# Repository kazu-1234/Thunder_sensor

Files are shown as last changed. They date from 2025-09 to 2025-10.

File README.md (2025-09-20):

# 多機能雷センサー for Raspberry Pi Pico 2 W

## 概要

Raspberry Pi Pico 2 Wを使用し、雷がどれくらいの距離で発生したかを推定し、同時に温度と湿度を常時監視します。収集したデータは、Wi-Fiを経由してGoogleスプレッドシートに自動的に記録されます。
雷は真上(1Km)～40Kmまで測定することができます。雷を受信すると距離がLINEに送信されるため、パソコンのリモートデスクトップ使用時など雷による被害を防ぐことができます。

またこのデバイスのボタン操作一つでSwitchBotに接続された照明やエアコン、テレビなどの家電を遠隔操作したり、パソコンをwake on lanで起動したりすることができます。

## インストール

### 1. 必要なもの（ハードウェア）
各コンポーネントの役割を理解することで、組み立てがスムーズになります。

   * **Raspberry Pi Pico W:** プロジェクト全体の頭脳。Wi-Fi機能を内蔵しており、ネットワーク通信を担います。
   * **雷センサーモジュール (SparkFun AS3935):** 雷が発する特有の電波を捉え、雷雲までのおおよその距離を算出します。人工的な電気ノイズと雷を区別する高度な機能を持ちます。
   * **温湿度センサー (DFRobot DHT20):** 周囲の温度と湿度を測定します。環境のモニタリングに不可欠です。
   * **LCDディスプレイ (I2C接続 20x4):** 測定データやメニュー、ステータスを表示する情報画面です。I2C接続タイプは少ない配線で済むのが利点です。
   * **その他:**
     - **タクトスイッチ:** ユーザーがメニューを操作するための入力装置です。
     - **フルカラーLED:** デバイスの状態（Wi-Fi接続中、雷検知など）を色で直感的に知らせます。
     - **抵抗、ブレッドボード、ジャンパーワイヤー:** 各部品を電気的に正しく接続するための基本的な電子工作部品です。

### 2. 必要なもの（ソフトウェア・ライブラリ）
Arduino IDEをプログラミング環境として使用します。

   * **Arduino IDE:** Raspberry Pi Picoボードパッケージを事前にインストールしておいてください。
   * **必要なライブラリ：** IDEのライブラリマネージャから以下のものをインストールします。
     - `WiFi`, `WiFiServer`, `WiFiClientSecure`, `HTTPClient`, `Wire`: Pico 2 Wの基本的なネットワーク機能とI2C通信に必要です。
     - `LiquidCrystal_I2C`: I2C接続のLCDを簡単に制御するために使用します。
     - `WiFiNTP`: 正確な時刻をインターネット経由で取得します。
     - `DFRobot_DHT20`: 温湿度センサーからのデータ読み取りに使用します。
     - `SparkFun AS3935 Lightning Detector`: 雷センサーを制御するための専用ライブラリです。
     - `ArduinoJson`: 外部APIとの通信データ（JSON形式）を扱うために重要です。
     - `ArduinoOTA`: Wi-Fi経由でプログラムを書き換える（無線アップデート）ために使用します。

### 3. 設定
ハードウェアとソフトウェアを連携させるための重要なステップです。

   * **ハードウェアの配線:** スケッチ（プログラムコード）内の`namespace Pins`セクションに、どの部品をPico 2 Wのどのピン（GP0, GP1など）に接続するかが定義されています。この定義通りに、ジャンパーワイヤーを使って正確に配線してください。特にI2Cデバイス（雷センサー、温湿度センサー、LCD）は、すべて同じSDA/SCLピンに並列で接続します。

   * **Google Apps Script:**
     1. Googleスプレッドシートを新規作成し、「拡張機能」メニューからApps Scriptを開きます。
     2. 提供されているスクリプトコードを貼り付け、プロジェクトを保存します。
     3. スクリプトを「ウェブアプリ」としてデプロイします。この際、アクセス権限を「全員」に設定しないと、Pico 2 Wからデータを受け取れないため注意してください。
     4. デプロイ後に生成される「ウェブアプリURL」を必ずコピーしておきます。

   * **Arduinoコード:**
     1. `pico_w_lightning_sensor_v5.6.ino` ファイルをArduino IDEで開きます。
     2. `★★★ 設定項目 ★★★`とコメントされているセクションを見つけ、以下の項目を自分の環境に合わせて書き換えます。
        - `GAS_URL`: 先ほどコピーしたGoogleのウェブアプリURLを貼り付けます。
        - `wifiCredentials`: 自宅のWi-FiのSSID（名前）とパスワードを入力します。
        - `SWITCHBOT_TOKEN`, `LINE_USER_ID`など: SwitchBotやLINE連携機能を使用する場合、各サービスで取得したAPIキーやトークンを設定します。

## 使い方

### 1. プログラムの書き込み
   * Arduino IDEで、ツールメニューからボードとして「Raspberry Pi Pico W」を選択します。
   * PCとPico WをUSBケーブルで接続します。初めて書き込む際は、Pico Wの「BOOTSEL」ボタンを押しながら接続し、PCに認識させてください。
   * IDEの書き込みボタン（→）をクリックし、コンパイルと書き込みが完了するのを待ちます。

### 2. 操作方法
書き込みが完了すると、デバイスは自動的に再起動し、動作を開始します。

   * **基本操作:**
     - **短く押す (タップ):** メニュー画面で、選択カーソルを次の項目へ移動させます。
     - **長く押す (1秒以上):**
       - メイン画面で：メニュー画面へ入ります。
       - メニュー画面で：選択中の項目を決定・実行します。
       - 各機能画面で：メイン画面へ戻ります。

   * **画面の見方:**
     - **メイン画面:** 起動後に表示される基本画面です。現在の日時、温度、湿度、そして最後に検知した雷イベント（距離またはノイズ）が表示され、一目で状況がわかります。
     - **メニュー画面:** ボタン長押しでアクセスします。ここから「デバイス操作」「時刻の再同期」「IPアドレスの表示」など、本機のすべての機能を選択できます。

## ライセンス

このプロジェクトは、[ライセンス名] ライセンスの下でライセンスされています。

## 更新履歴

* 2025/09/10: [v5.6 - ディスターバー検知機能の追加と安定性の向上]

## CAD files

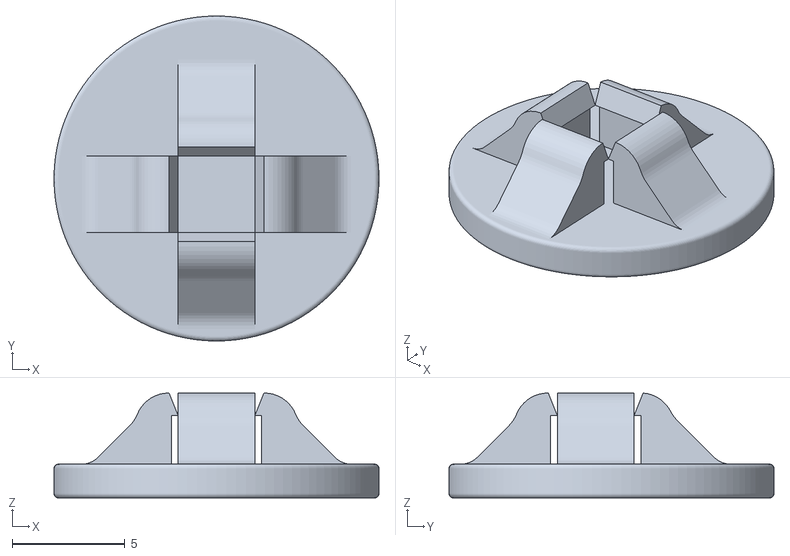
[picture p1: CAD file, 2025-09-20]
3D_data/Thunder_sensor_button.stl
14.4 x 14.4 x 4.65

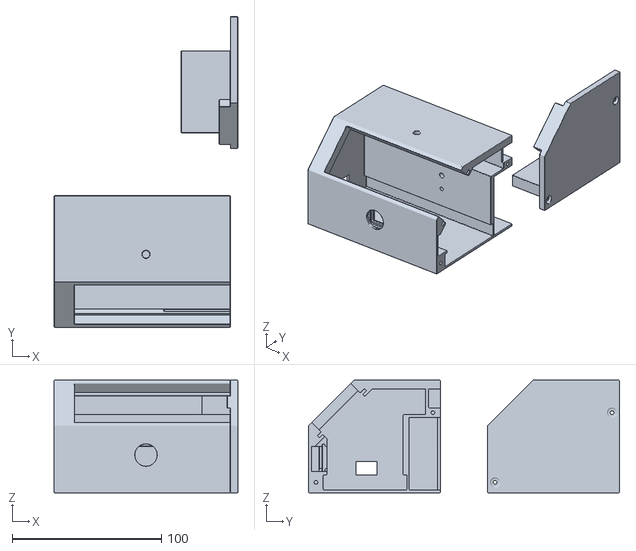
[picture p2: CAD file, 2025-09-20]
3D_data/Thunder_sensor.stl
123.0 x 208.4 x 75.5

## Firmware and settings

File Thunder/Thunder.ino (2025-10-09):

// Ver 8.8
//================================================================
// ライブラリ
//================================================================
#include <WiFi.h>
#include <WiFiServer.h>
#include <WiFiClientSecure.h>
#include <HTTPClient.h>
#include <Wire.h>
#include <LiquidCrystal.h>
#include <time.h>
#include <stdlib.h>
#include <WiFiNTP.h>
#include <DFRobot_DHT20.h>
#include <SparkFun_AS3935.h>
#include <ArduinoJson.h>
#include <WiFiUdp.h>
#include <LittleFS.h>
#include <math.h>       // for round()
#include <ArduinoOTA.h> // 標準の無線書き込み(OTA)用ライブラリ

// ★追加: 設定ファイルを読み込む
#include "config.h"

//================================================================
// ★★★ 設定項目 (本体の動作設定) ★★★
//================================================================
// --- 雷センサー感度設定 ---
const uint8_t LIGHTNING_WATCHDOG_THRESHOLD = 1; // 雷検知の強さの閾値 (調整範囲: 1～10)
const uint8_t LIGHTNING_SPIKE_REJECTION = 1;    // 電気的ノイズの除去レベル (調整範囲: 1～11)
const uint8_t INITIAL_NOISE_LEVEL = 1;          // 周囲の環境ノイズの初期レベル (調整範囲: 1～7)

// --- 動作設定 ---
const unsigned long LONG_PRESS_DURATION_MS = 1000;
const unsigned long INACTIVITY_TIMEOUT_MS = 5000;
const unsigned long BACKLIGHT_DURATION_MS = 3000;
const unsigned long SENSOR_READ_INTERVAL_MS = 2000; // センサー読み取り間隔
const unsigned long IP_DISPLAY_DURATION_MS = 5000;
const int HISTORY_SIZE = 3;
const int LCD_COLS = 20;
const int LCD_ROWS = 4;

//================================================================
// ピン定義
//================================================================
namespace Pins
{
    const int LCD_RS = 2, LCD_E = 3, LCD_D4 = 4, LCD_D5 = 5, LCD_D6 = 6, LCD_D7 = 7;
    const int LCD_BACKLIGHT = 14;
    const int LED_R = 28, LED_G = 27, LED_B = 26;
    const int BUTTON = 15;
    const int I2C_SDA = 0, I2C_SCL = 1;
    const int LIGHTNING_IRQ = 16;
    const int AS3935_ADDR = 0x03;
}

//================================================================
// グローバル状態管理
//================================================================
namespace State
{
    // --- 動作モード ---
    enum Mode
    {
        MAIN_DISPLAY,
        MENU,
        HISTORY,
        SWITCHBOT_APPLIANCE_SELECT,
        DEVICE_CONTROL,
        WAKE_ON_LAN,
        ULTRASONIC_MONITOR,
        SENSOR_DIAGNOSTICS
    };

    // --- メニューの状態 ---
    struct MenuState
    {
        Mode currentMode = MAIN_DISPLAY;
        int menuSelection = 0;
        int deviceSelection = 0;
        int commandSelection = 0;
    };

    // --- システムの状態 ---
    struct SystemState
    {
        bool illuminationOn = false;
        bool backlightAlwaysOn = false;
        bool ntpInitialized = false;
        bool isAutoResync = false;
        bool needsRedraw = true;
        bool forceMainScreenRedraw = true;
        uint8_t currentNoiseLevel = 2;
        bool initialLogSent = false;
        bool pendingLightningLog = false;
        bool dht20_initialized = false;
        bool as3935_initialized = false;
    };

    // --- センサーデータ ---
    struct SensorData
    {
        float temperature = -999.0;
        float humidity = -999.0;
        float ultrasonicDistance = -1.0;
        char lastEventTime[20] = "N/A";
        String lastEventType = "None"; // "Lightning" or "Noise"
        int lastLightningDistance = -1;
    };

    // --- 本体メモリに記録する雷履歴 ---
    struct EventRecord
    {
        char timestamp[20];
        String type;
        int distance;
    };

    struct HistoryState
    {
        EventRecord records[HISTORY_SIZE];
        int index = 0;
        int count = 0;
    };

    // --- タイマー ---
    struct TimerState
    {
        unsigned long lastActivity = 0;
        unsigned long backlightOn = 0;
    };

    // --- 暗号化コンテキスト ---
    struct SHA256_CTX
    {
        uint8_t data[64];
        uint32_t datalen;
        uint64_t bitlen;
        uint32_t state[8];
    };

    // --- グローバルオブジェクトと状態変数のインスタンス ---
    MenuState menu;
    SystemState system;
    SensorData sensors;
    HistoryState history;
    TimerState timers;

    LiquidCrystal lcd(Pins::LCD_RS, Pins::LCD_E, Pins::LCD_D4, Pins::LCD_D5, Pins::LCD_D6, Pins::LCD_D7);
    DFRobot_DHT20 dht20;
    SparkFun_AS3935 lightning(Pins::AS3935_ADDR);
    WiFiServer server(80);
    String childIpAddress = "";
    volatile bool lightningInterruptFlag = false;
}

//================================================================
// 暗号化ユーティリティ (編集不要)
//================================================================
namespace Crypto
{
    const uint32_t K[64] = {0x428a2f98, 0x71374491, 0xb5c0fbcf, 0xe9b5dba5, 0x3956c25b, 0x59f111f1, 0x923f82a4, 0xab1c5ed5, 0xd807aa98, 0x12835b01, 0x243185be, 0x550c7dc3, 0x72be5d74, 0x80deb1fe, 0x9bdc06a7, 0xc19bf174, 0xe49b69c1, 0xefbe4786, 0x0fc19dc6, 0x240ca1cc, 0x2de92c6f, 0x4a7484aa, 0x5cb0a9dc, 0x76f988da, 0x983e5152, 0xa831c66d, 0xb00327c8, 0xbf597fc7, 0xc6e00bf3, 0xd5a79147, 0x06ca6351, 0x14292967, 0x27b70a85, 0x2e1b2138, 0x4d2c6dfc, 0x53380d13, 0x650a7354, 0x766a0abb, 0x81c2c92e, 0x92722c85, 0xa2bfe8a1, 0xa81a664b, 0xc24b8b70, 0xc76c51a3, 0xd192e819, 0xd6990624, 0xf40e3585, 0x106aa070, 0x19a4c116, 0x1e376c08, 0x2748774c, 0x34b0bcb5, 0x391c0cb3, 0x4ed8aa4a, 0x5b9cca4f, 0x682e6ff3, 0x748f82ee, 0x78a5636f, 0x84c87814, 0x8cc70208, 0x90befffa, 0xa4506ceb, 0xbef9a3f7, 0xc67178f2};
    uint32_t rotr(uint32_t x, uint32_t n) { return (x >> n) | (x << (32 - n)); }
    void sha256_transform(State::SHA256_CTX *ctx, const uint8_t data[])
    {
        uint32_t a, b, c, d, e, f, g, h, i, j, t1, t2, m[64];
        for (i = 0, j = 0; i < 16; ++i, j += 4)
            m[i] = (data[j] << 24) | (data[j + 1] << 16) | (data[j + 2] << 8) | (data[j + 3]);
        for (; i < 64; ++i)
            m[i] = (((m[i - 2] >> 17) | (m[i - 2] << 15)) ^ ((m[i - 2] >> 19) | (m[i - 2] << 13)) ^ (m[i - 2] >> 10)) + m[i - 7] + (((m[i - 15] >> 7) | (m[i - 15] << 25)) ^ ((m[i - 15] >> 18) | (m[i - 15] << 14)) ^ (m[i - 15] >> 3)) + m[i - 16];
        a = ctx->state[0];
        b = ctx->state[1];
        c = ctx->state[2];
        d = ctx->state[3];
        e = ctx->state[4];
        f = ctx->state[5];
        g = ctx->state[6];
        h = ctx->state[7];
        for (i = 0; i < 64; ++i)
        {
            t1 = h + (((e >> 6) | (e << 26)) ^ ((e >> 11) | (e << 21)) ^ ((e >> 25) | (e << 7))) + ((e & f) ^ (~e & g)) + K[i] + m[i];
            t2 = (((a >> 2) | (a << 30)) ^ ((a >> 13) | (a << 19)) ^ ((a >> 22) | (a << 10))) + ((a & b) ^ (a & c) ^ (b & c));
            h = g;
            g = f;
            f = e;
            e = d + t1;
            d = c;
            c = b;
            b = a;
            a = t1 + t2;
        }
        ctx->state[0] += a;
        ctx->state[1] += b;
        ctx->state[2] += c;
        ctx->state[3] += d;
        ctx->state[4] += e;
        ctx->state[5] += f;
        ctx->state[6] += g;
        ctx->state[7] += h;
    }
    void sha256_init(State::SHA256_CTX *ctx)
    {
        ctx->datalen = 0;
        ctx->bitlen = 0;
        ctx->state[0] = 0x6a09e667;
        ctx->state[1] = 0xbb67ae85;
        ctx->state[2] = 0x3c6ef372;
        ctx->state[3] = 0xa54ff53a;
        ctx->state[4] = 0x510e527f;
        ctx->state[5] = 0x9b05688c;
        ctx->state[6] = 0x1f83d9ab;
        ctx->state[7] = 0x5be0cd19;
    }
    void sha256_update(State::SHA256_CTX *ctx, const uint8_t data[], size_t len)
    {
        for (uint32_t i = 0; i < len; ++i)
        {
            ctx->data[ctx->datalen] = data[i];
            ctx->datalen++;
            if (ctx->datalen == 64)
            {
                sha256_transform(ctx, ctx->data);
                ctx->bitlen += 512;
                ctx->datalen = 0;
            }
        }
    }
    void sha256_final(State::SHA256_CTX *ctx, uint8_t hash[])
    {
        uint32_t i = ctx->datalen;
        if (ctx->datalen < 56)
        {
            ctx->data[i++] = 0x80;
            while (i < 56)
                ctx->data[i++] = 0x00;
        }
        else
        {
            ctx->data[i++] = 0x80;
            while (i < 64)
                ctx->data[i++] = 0x00;
            sha256_transform(ctx, ctx->data);
            memset(ctx->data, 0, 56);
        }
        ctx->bitlen += ctx->datalen * 8;
        ctx->data[63] = ctx->bitlen;
        ctx->data[62] = ctx->bitlen >> 8;
        ctx->data[61] = ctx->bitlen >> 16;
        ctx->data[60] = ctx->bitlen >> 24;
        ctx->data[59] = ctx->bitlen >> 32;
        ctx->data[58] = ctx->bitlen >> 40;
        ctx->data[57] = ctx->bitlen >> 48;
        ctx->data[56] = ctx->bitlen >> 56;
        sha256_transform(ctx, ctx->data);
        for (i = 0; i < 4; ++i)
        {
            hash[i] = (ctx->state[0] >> (24 - i * 8)) & 0xff;
            hash[i + 4] = (ctx->state[1] >> (24 - i * 8)) & 0xff;
            hash[i + 8] = (ctx->state[2] >> (24 - i * 8)) & 0xff;
            hash[i + 12] = (ctx->state[3] >> (24 - i * 8)) & 0xff;
            hash[i + 16] = (ctx->state[4] >> (24 - i * 8)) & 0xff;
            hash[i + 20] = (ctx->state[5] >> (24 - i * 8)) & 0xff;
            hash[i + 24] = (ctx->state[6] >> (24 - i * 8)) & 0xff;
            hash[i + 28] = (ctx->state[7] >> (24 - i * 8)) & 0xff;
        }
    }
    void hmac_sha256(const uint8_t *key, size_t keylen, const uint8_t *data, size_t datalen, uint8_t *out)
    {
        State::SHA256_CTX ctx;
        uint8_t k_ipad[65], k_opad[65], tk[32];
        memset(k_ipad, 0, sizeof(k_ipad));
        memset(k_opad, 0, sizeof(k_opad));
        if (keylen > 64)
        {
            sha256_init(&ctx);
            sha256_update(&ctx, key, keylen);
            sha256_final(&ctx, tk);
            key = tk;
            keylen = 32;
        }
        memcpy(k_ipad, key, keylen);
        memcpy(k_opad, key, keylen);
        for (int i = 0; i < 64; i++)
        {
            k_ipad[i] ^= 0x36;
            k_opad[i] ^= 0x5c;
        }
        sha256_init(&ctx);
        sha256_update(&ctx, k_ipad, 64);
        sha256_update(&ctx, data, datalen);
        sha256_final(&ctx, out);
        sha256_init(&ctx);
        sha256_update(&ctx, k_opad, 64);
        sha256_update(&ctx, out, 32);
        sha256_final(&ctx, out);
    }
    String base64_encode(const uint8_t *data, size_t len)
    {
        static const char *b64_table = "ABCDEFGHIJKLMNOPQRSTUVWXYZabcdefghijklmnopqrstuvwxyz0123456789+/";
        String ret;
        ret.reserve((len + 2) / 3 * 4);
        for (size_t i = 0; i < len; i += 3)
        {
            uint32_t octet_a = i < len ? data[i] : 0;
            uint32_t octet_b = i + 1 < len ? data[i + 1] : 0;
            uint32_t octet_c = i + 2 < len ? data[i + 2] : 0;
            uint32_t triple = (octet_a << 0x10) + (octet_b << 0x08) + octet_c;
            ret += b64_table[(triple >> 3 * 6) & 0x3F];
            ret += b64_table[(triple >> 2 * 6) & 0x3F];
            ret += b64_table[(triple >> 1 * 6) & 0x3F];
            ret += b64_table[(triple >> 0 * 6) & 0x3F];
        }
        if (len % 3 == 1)
        {
            ret[ret.length() - 1] = '=';
            ret[ret.length() - 2] = '=';
        }
        if (len % 3 == 2)
        {
            ret[ret.length() - 1] = '=';
        }
        return ret;
    }
}

//================================================================
// プロトタイプ宣言
//================================================================
namespace Menu
{
    void changeMode(State::Mode newMode);
}
namespace Display
{
    void printLcdLine(int line, const char *text);
    void updateMainDisplay();
}
namespace Network
{
    void sendSwitchBotCommand(const char *deviceId, const char *command, const char *parameter, const char *commandType = "command");
    void resyncNtpTime();
    void getSwitchBotDeviceList();
    void sendLineTestMessage();
    void sendWakeOnLan(const char *macStr);
    void requestDistance();
    void showIpAddressAndHold();
    void logDataToGoogleSheet(String params);
    void manualLogToSheet();
    bool connectToWiFi(bool showOnLcd);
    void checkWiFiConnection();
    void handleNtpSync();
}
namespace Utils
{
    void toggleBacklightMode();
    void toggleIlluminationMode();
    void rebootDevice();
}
namespace Sensors
{
    void init();
    void calibrateSensor();
    void updateDht();
}
void handlePeriodicTasks();
void handlePendingNetworkTasks();
void handleFourSecondCycle();

//================================================================
// メニュー定義
//================================================================
namespace Menu
{
    struct MenuItem
    {
        const char *text;
        void (*action)();
    };
    void performMenuAction(void (*action)(), bool returnToMain);

    void enterHistory() { changeMode(State::HISTORY); }
    void enterSwitchbotMenu() { changeMode(State::SWITCHBOT_APPLIANCE_SELECT); }
    void enterWakeOnLan() { changeMode(State::WAKE_ON_LAN); }
    void enterUltrasonic() { changeMode(State::ULTRASONIC_MONITOR); }
    void enterDiagnostics() { changeMode(State::SENSOR_DIAGNOSTICS); }
    void enterDeviceControl()
    {
        State::menu.deviceSelection = State::menu.menuSelection;
        State::menu.commandSelection = 0;
        changeMode(State::DEVICE_CONTROL);
    }

// Small helpers to reduce repetitive lambda boilerplate in menus
#define PM(action, ret) ([]() { performMenuAction(action, ret); })
#define SB(dev, cmd, param, type, ret) ([]() { performMenuAction([]() { Network::sendSwitchBotCommand(dev, cmd, param, type); }, ret); })
#define SB_DEF(dev, cmd, param, ret) SB(dev, cmd, param, "command", ret)
// helper to call arbitrary statement(s) inside performMenuAction
#define PM_CALL(call, ret) ([]() { performMenuAction([]() { call; }, ret); })
    const MenuItem mainMenu[] = {
        {"1. Lightning Log", enterHistory},
        {"2. Device Control", enterSwitchbotMenu},
        {"3. Wake on LAN", enterWakeOnLan},
        {"4. Backlight Mode", PM(Utils::toggleBacklightMode, true)},
        {"5. RGB Illumination", PM(Utils::toggleIlluminationMode, true)},
        {"6. Measure Dist", enterUltrasonic},
        {"7. Resync Time", PM(Network::resyncNtpTime, true)},
        {"8. Show IP Address", PM_CALL(Network::showIpAddressAndHold(); Menu::changeMode(State::MAIN_DISPLAY), false)},
        {"9. Get SwitchBot IDs", PM(Network::getSwitchBotDeviceList, true)},
        {"10. Send LINE Test", PM(Network::sendLineTestMessage, true)},
        {"11. Log Data Manually", PM(Network::manualLogToSheet, true)},
        {"12. Reboot", Utils::rebootDevice},
        {"13. Sensor Diag", enterDiagnostics},
        {"14. Calibrate Sensor", PM(Sensors::calibrateSensor, true)}};
    const int MAIN_MENU_COUNT = sizeof(mainMenu) / sizeof(mainMenu[0]);

    const MenuItem applianceMenu[] = {
        {"1. Light", enterDeviceControl}, {"2. TV", enterDeviceControl}, {"3. Air Conditioner", enterDeviceControl}, {"4. Fan", enterDeviceControl}, {"5. Speaker", enterDeviceControl}, {"6. Others", enterDeviceControl}, {"7. Back", []()
                                                                                                                                                                                                                             { changeMode(State::MENU); }}};
    const int APPLIANCE_MENU_COUNT = sizeof(applianceMenu) / sizeof(applianceMenu[0]);

    const MenuItem wolMenu[] = {
        {"1. Desktop PC", PM_CALL(Network::sendWakeOnLan(MAC_DESKTOP), true)},
        {"2. Server PC", PM_CALL(Network::sendWakeOnLan(MAC_SERVER), true)}};
    const int WOL_MENU_COUNT = sizeof(wolMenu) / sizeof(wolMenu[0]);

    const MenuItem lightControlMenu[] = {
        {"On", SB_DEF(DEVICE_ID_LIGHT, "turnOn", "default", false)},
        {"Off", SB_DEF(DEVICE_ID_LIGHT, "turnOff", "default", false)},
        {"Bright+", SB_DEF(DEVICE_ID_LIGHT, "brightnessUp", "default", false)},
        {"Bright-", SB_DEF(DEVICE_ID_LIGHT, "brightnessDown", "default", false)},
        {"Warm", SB_DEF(DEVICE_ID_LIGHT, "setColorTemperature", "2700", false)},
        {"White", SB_DEF(DEVICE_ID_LIGHT, "setColorTemperature", "6500", false)},
        {"Back", []()
         { changeMode(State::SWITCHBOT_APPLIANCE_SELECT); }}};
    const MenuItem tvControlMenu[] = {
        {"Power", SB_DEF(DEVICE_ID_TV, "turnOn", "default", false)},
        {"CH +", SB_DEF(DEVICE_ID_TV, "channelAdd", "default", false)},
        {"CH -", SB_DEF(DEVICE_ID_TV, "channelSub", "default", false)},
        {"Vol +", SB_DEF(DEVICE_ID_TV, "volumeAdd", "default", false)},
        {"Vol -", SB_DEF(DEVICE_ID_TV, "volumeSub", "default", false)},
        {"Back", []()
         { changeMode(State::SWITCHBOT_APPLIANCE_SELECT); }}};
    const MenuItem acControlMenu[] = {
        {"Run", SB_DEF(DEVICE_ID_AC, "turnOn", "default", false)},
        {"Stop", SB_DEF(DEVICE_ID_AC, "turnOff", "default", false)},
        {"Temp +", SB_DEF(DEVICE_ID_AC, "setTemperature", "26,auto,1,on", false)},
        {"Temp -", SB_DEF(DEVICE_ID_AC, "setTemperature", "24,auto,1,on", false)},
        {"Cooling", SB_DEF(DEVICE_ID_AC, "setAll", "25,2,1,on", false)},
        {"Heating", SB_DEF(DEVICE_ID_AC, "setAll", "22,5,1,on", false)},
        {"Dehumidify", SB_DEF(DEVICE_ID_AC, "setAll", "25,3,1,on", false)},
        {"Back", []()
         { changeMode(State::SWITCHBOT_APPLIANCE_SELECT); }}};
    const MenuItem fanControlMenu[] = {
        {"On", SB_DEF(DEVICE_ID_FAN, "press", "運転", false)},
        {"Off", SB_DEF(DEVICE_ID_FAN, "press", "切/入", false)},
        {"Speed +", SB_DEF(DEVICE_ID_FAN, "press", "風量+", false)},
        {"Speed -", SB_DEF(DEVICE_ID_FAN, "press", "風量-", false)},
        {"Swing", SB_DEF(DEVICE_ID_FAN, "press", "スウィング", false)},
        {"Back", []()
         { changeMode(State::SWITCHBOT_APPLIANCE_SELECT); }}};
    const MenuItem speakerControlMenu[] = {
        {"Power", SB_DEF(DEVICE_ID_SPEAKER, "press", "Power", false)},
        {"Vol +", SB_DEF(DEVICE_ID_SPEAKER, "volumeAdd", "default", false)},
        {"Vol -", SB_DEF(DEVICE_ID_SPEAKER, "volumeSub", "default", false)},
        {"Prev", SB_DEF(DEVICE_ID_SPEAKER, "previousTrack", "default", false)},
        {"Next", SB_DEF(DEVICE_ID_SPEAKER, "nextTrack", "default", false)},
        {"Back", []()
         { changeMode(State::SWITCHBOT_APPLIANCE_SELECT); }}};
    const MenuItem othersControlMenu[] = {
        {"Command 1", SB_DEF(DEVICE_ID_OTHERS, "turnOn", "default", false)},
        {"Command 2", SB_DEF(DEVICE_ID_OTHERS, "turnOff", "default", false)},
        {"Back", []()
         { changeMode(State::SWITCHBOT_APPLIANCE_SELECT); }}};

    const MenuItem *const applianceControlMenus[] = {lightControlMenu, tvControlMenu, acControlMenu, fanControlMenu, speakerControlMenu, othersControlMenu};
    const int applianceControlMenuCounts[] = {7, 6, 8, 6, 6, 3};

    const MenuItem *getCurrentMenu(int &count, int &selection)
    {
        switch (State::menu.currentMode)
        {
        case State::MENU:
            count = MAIN_MENU_COUNT;
            selection = State::menu.menuSelection;
            return mainMenu;
        case State::SWITCHBOT_APPLIANCE_SELECT:
            count = APPLIANCE_MENU_COUNT;
            selection = State::menu.menuSelection;
            return applianceMenu;
        case State::WAKE_ON_LAN:
            count = WOL_MENU_COUNT;
            selection = State::menu.menuSelection;
            return wolMenu;
        case State::DEVICE_CONTROL:
            if (State::menu.deviceSelection < sizeof(applianceControlMenus) / sizeof(MenuItem **))
            {
                count = applianceControlMenuCounts[State::menu.deviceSelection];
                selection = State::menu.commandSelection;
                return applianceControlMenus[State::menu.deviceSelection];
            }
        default:
            count = 0;
            selection = 0;
            return nullptr;
        }
    }
}
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
void loop()
{
    // --- 毎ループ実行する必要がある処理 ---
    ArduinoOTA.handle();     // OTA（無線書き込み）の待機
    Input::handleButton();   // ボタン入力の処理
    Network::update();       // WiFi接続と時刻同期をバックグラウンドで処理
    Sensors::update();       // 雷割り込みフラグのチェック
    Display::update();       // 画面描画
    Menu::checkInactivity(); // メニューのタイムアウトチェック

    // --- 4秒サイクルのタスク管理 ---
    handleFourSecondCycle(); // 温湿度読み取りなどを管理

    // --- 定期実行・不定期実行のタスク ---
    handlePeriodicTasks();       // 10分ごとのデータ記録など
    handlePendingNetworkTasks(); // 雷検知時の通知など

    // --- その他の常時処理 ---
    if (State::system.illuminationOn)
    {
        Utils::handleSmoothIllumination();
    }

    if (State::menu.currentMode == State::MAIN_DISPLAY && !State::system.backlightAlwaysOn &&
        State::timers.backlightOn > 0 && (millis() - State::timers.backlightOn > BACKLIGHT_DURATION_MS))
    {
        digitalWrite(Pins::LCD_BACKLIGHT, LOW);
        State::timers.backlightOn = 0;
    }
}
